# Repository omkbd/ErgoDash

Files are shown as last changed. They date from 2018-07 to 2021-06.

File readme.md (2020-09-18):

# Notice

2019/5/5にファームウェアをアップデートしました。  
それ以前にハードウェアを作製されていた方はアップデートの必要はありませんが、  
アップデートした方は[ビルドガイドの最終項](https://github.com/omkbd/ErgoDash/blob/master/Doc/build.md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)を参照してください。

The firmware has been updated to 5/5/2019.  
If you have previously created hardware, you do not need to update, but if you have updated, please refer to [the last section of the build guide](https://github.com/omkbd/ErgoDash/blob/master/Doc/build-en.md#12-firmware).

# ErgoDash

ErgoDash

[Japanese Read me](https://github.com/omkbd/ErgoDash/blob/master/Doc/ergodash_jp.md)

# Layout

layout

# Parts

[ErgoDash PCB](https://github.com/omkbd/ErgoDash/tree/master/PCB)
 × 2  
[ErgoDash Case](https://github.com/omkbd/ErgoDash/tree/master/Case)
 × 2  
Switch (MX-compatible and Alps switches are supported) × 66-70  
Keycap × 66-70  
1N4148 diode × 66-70  
Arduino Pro Micro × 2  
TRRS jack MJ-4PP-9 × 2  
MJTP1117 switch × 2  
TRRS cable × 1  
Micro USB cable × 1  
M2×5mm screw × 22  
M2×8mm screw × 6  
M2×6mm spacer × 14  
Rubber feet × 8

---Option---  
LED WS2812B × 24  
LED 3mm × 66-70  
470Ω resistor × 66-70  
1kΩ resistor × 2  
NchMOSFET IRLML6344TRPbF × 2  

# Firmware

The ErgoDash uses QMK for its firmware, and the code for it is here:
[QMK - ErgoDash directory](https://github.com/qmk/qmk_firmware/tree/master/keyboards/ergodash)
.  

# Build Guide

[Japanese Build Guide](https://github.com/omkbd/ErgoDash/blob/master/Doc/build.md)  
[English Build Guide](https://github.com/omkbd/ErgoDash/blob/master/Doc/build-en.md)

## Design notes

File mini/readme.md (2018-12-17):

# ErgoDash mini

ErgoDash

[Japanese Read me](https://github.com/omkbd/ErgoDash/blob/master/mini/Doc/ergodashmini_jp.md)

# Layout

layout

# Parts

[ErgoDash mini PCB](https://github.com/omkbd/ErgoDash/tree/master/mini/PCB)
 × 2  
[ErgoDash mini Case](https://github.com/omkbd/ErgoDash/tree/master/mini/Case)
 × 2  
Switch (MX-compatible and Alps switches are supported) × 56  
Keycap × 56  
1N4148 diode × 56  
Arduino Pro Micro × 2  
TRRS jack MJ-4PP-9 × 2  
MJTP1117 switch × 2  
TRRS cable × 1  
Micro USB cable × 1  
M2 screw × 28  
M2 spacer × 14  

---Option---  
LED WS2812B × 20  
LED 3mm × 56  
470Ω resistor × 56  
1kΩ resistor × 2  
NchMOSFET IRLML6344TRPbF × 2  

You can get it
[here](https://dashkbd.booth.pm/items/1011978)
.

# Firmware

The ErgoDash uses QMK for its firmware, and the code for it is here:
[QMK - ErgoDash mini directory](https://github.com/qmk/qmk_firmware/tree/master/keyboards/ergodash/mini)
.  

# Build Guide

Look
[here](https://github.com/omkbd/ErgoDash/blob/master/mini/Doc/build.md)
.

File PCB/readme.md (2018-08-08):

# ErgoDash PCB

ErgoDash PCB  

## 変更履歴

### [rev.1.1]
・圧電スピーカーを追加（試験的）  
・上記に伴うパーツの配置を調整  
・シルク表記を追加

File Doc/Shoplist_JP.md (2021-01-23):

# ErgoDashの買い物リスト[国内]

Cherry MX 互換 スイッチ × 66～70  
https://yushakobo.jp/product-category/switches/  
https://talpkeyboard.stores.jp/?category_id=59cf8860ed05e668db003f5d  

Keycap × 66～70 (基本的に1uのみで構成可、配列によって2uに変更)  
https://talpkeyboard.stores.jp/?category_id=59be183f428f2d49120007b1  
https://talpkeyboard.stores.jp/?category_id=59e2acfaed05e644fd004008  

1N4148 ダイオード × 66～70  
http://akizukidenshi.com/catalog/g/gI-00743/  
https://talpkeyboard.stores.jp/items/59eadbffc8f22c15de001638  

Pro Micro × 2  
https://www.switch-science.com/catalog/1623/  
https://yushakobo.jp/shop/promicro-spring-pinheader/  
https://talpkeyboard.stores.jp/items/5b24504ba6e6ee7ec60063e3

TRRS jack MJ-4PP-9 × 2  
http://akizukidenshi.com/catalog/g/gC-06070/

MJTP1117 switch × 2  
https://www.marutsu.co.jp/pc/i/13351221/  
https://www.digikey.jp/product-detail/ja/apem-inc/MJTP1117/679-2400-ND/1795496  

TRRS cable × 1 (RGB Underglowを使用する場合4極が必要)  
https://www.sengoku.co.jp/mod/sgk_cart/detail.php?code=EEHD-4Z7Y  
https://www.sengoku.co.jp/mod/sgk_cart/detail.php?code=EEHD-4Z84  
https://www.sengoku.co.jp/mod/sgk_cart/detail.php?code=EEHD-4Z87  

Micro USB cable × 1  

M2×5mm ねじ × 22  

M2×8mm ねじ × 6  

M2×6mm スペーサー × 14  
http://www.hirosugi-net.co.jp/shop/c/c10141010/

ゴム足 × 8  

------Option------  
スプリングピンヘッダ12P × 4 ([Helix](https://github.com/MakotoKurauchi/helix)で使用されているものです。)  
https://yushakobo.jp/shop/a01mc-00/  

---Backlight---  
LED 3mm × 66～70  
例(実機未確認)
https://akizukidenshi.com/catalog/c/ctbn3mm/

https://www.aitendo.com/product/10043
(BOXスイッチの場合)

470Ω resistor × 66～70  
http://akizukidenshi.com/catalog/g/gR-16471/  
1kΩ resistor × 2  
http://akizukidenshi.com/catalog/g/gR-16102/  
NchMOSFET IRLML6344TRPbF × 2  
http://akizukidenshi.com/catalog/g/gI-06049/  

---RGB Underglow---  
LED WS2812B × 24  
http://akizukidenshi.com/catalog/g/gI-07915/

又は  
LEDテープ × 2

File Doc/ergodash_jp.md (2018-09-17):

# ErgoDashについて

ErgoDash

## 特徴
・左右分離型  
・Column staggered layout  
・66～70キー（最下段をカスタマイズ可能、最大64パターン?）  
・Cherry MX 互換スイッチ対応  
・Backlight LED対応  
・RGB Underglow対応  
・QMK Firmware 対応  

## キー配列

layout  
上の図が可能な配列です。（わかりにくくてすみません。）  
片手で10パターン、両手で100パターンの配列が選択可能です。  
※両手を同じ配列にする必要はありません。

## パーツ

[ErgoDash PCB](https://github.com/omkbd/ErgoDash/tree/master/PCB)
 × 2  
[ErgoDash Case](https://github.com/omkbd/ErgoDash/tree/master/Case)
 × 2  
Cherry MX 互換 スイッチ × 66～70  
Keycap × 66～70 (基本的に1uのみで構成可、配列によって2uに変更)  
1N4148 ダイオード × 66～70  
Pro Micro × 2  
TRRS jack MJ-4PP-9 × 2  
MJTP1117 switch × 2  
TRRS cable × 1 (RGB Underglowを使用する場合4極が必要)  
Micro USB cable × 1  
M2×5mm ねじ × 22  
M2×8mm ねじ × 6  
M2×6mm スペーサー × 14  
ゴム足 × 8  

------Option------  
スプリングピンヘッダ12P × 4 ([Helix](https://github.com/MakotoKurauchi/helix)で使用されているものです。)  
---Backlight---  
LED 3mm × 66～70  
470Ω resistor × 66～70  
1kΩ resistor × 2  
NchMOSFET IRLML6344TRPbF × 2  
---RGB Underglow---  
LED WS2812B × 24  
又は  
LEDテープ × 2

PCBとケース以外は基本的に国内サイトで入手可能です。  
[ここ](https://dashkbd.booth.pm/items/1011978)
で基本セットを販売しています。

## ファームウェア

QMK Firmwareで動作します。
[QMK - ErgoDash directory](https://github.com/qmk/qmk_firmware/tree/master/keyboards/ergodash)
.  

## 組み立て方

[ここ](https://github.com/omkbd/ErgoDash/blob/master/Doc/build.md)
を見てください。

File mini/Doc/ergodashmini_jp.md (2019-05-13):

# ErgoDash miniについて

ErgoDash mini

## 特徴
・左右分離型  
・Column staggered layout  
・52～56キー（最下段をカスタマイズ可能、最大100パターン）  
・Cherry MX 互換スイッチ対応  
・Backlight LED対応  
・RGB Underglow対応  
・QMK Firmware 対応  

## キー配列

layout  
上の図が可能な配列です。（わかりにくくてすみません。）  
片手で10パターン、両手で100パターンの配列が選択可能です。  
※両手を同じ配列にする必要はありません。

## パーツ

[ErgoDash mini PCB](https://github.com/omkbd/ErgoDash/tree/master/mini/PCB)
 × 2  
[ErgoDash mini Case](https://github.com/omkbd/ErgoDash/tree/master/mini/Case)
 × 2  
Cherry MX 互換 スイッチ × 56  
Keycap × 56 (基本的に1uのみで構成可、配列によって2uに変更)  
1N4148 ダイオード × 56  
Pro Micro × 2  
TRRS jack MJ-4PP-9 × 2  
MJTP1117 switch × 2  
TRRS cable × 1 (RGB Underglowを使用する場合4極が必要)  
Micro USB cable × 1  
M2×5mm ねじ × 22  
M2×8mm ねじ × 6  
M2×6mm スペーサー × 14  
ゴム足 × 8  

------Option------  
スプリングピンヘッダ12P × 4 ([Helix](https://github.com/MakotoKurauchi/helix)で使用されているものです。)  
---Backlight---  
LED 3mm × 56  
470Ω resistor × 56  
1kΩ resistor × 2  
NchMOSFET IRLML6344TRPbF × 2  
---RGB Underglow---  
LED WS2812B × 20  
又は  
LEDテープ × 2

PCBとケース以外は基本的に国内サイトで入手可能です。  
[ここ](https://dashkbd.booth.pm/items/1011978)
で基本セットを販売しています。(準備中)

## ファームウェア

QMK Firmwareで動作します。
[QMK - ErgoDash mini directory](https://github.com/qmk/qmk_firmware/tree/master/keyboards/ergodash/mini)
.  

## 組み立て方

[ここ](https://github.com/omkbd/ErgoDash/blob/master/mini/Doc/build.md)
を見てください。

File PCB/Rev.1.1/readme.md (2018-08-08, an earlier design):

# ErgoDash PCB

このPCBデータはQMK Fimware上のRev.2に対応しています。  

ErgoDash PCB  

### ① pro micro
2か所のうちのどちらか一方に取り付けます。  
シルクが印刷されているほうに取り付けると、コネクタの高さ分ケースを薄くできます。  
### ② MJTP1117 :Reset switch
①で取り付けた位置と逆に取り付けます。  
### ③TRRS jack
シルクに合わせて実装します。
### ④Cherry MX 互換スイッチ  
### ⑤Diode
向きがあるので注意しましょう。  
　　●　　Anode（アノード）  
　　｜  
　　■　　Anode（アノード）SMD用  
　　▽  
　　■　　Cathode（カソード）SMD用  
　　｜  
　　■　　Cathode（カソード）  
### ⑥470Ω resistor（抵抗）  
　　●  
　　｜  
　　■  
　　／  
　　■  
　　｜  
　　●  
### ⑦LED
向きがあるので注意しましょう。  
　　●　　Anode（アノード）  
　　■　　Cathode（カソード）  
### ⑧1kΩ resistor（抵抗）
この一か所のみです。  
　　●  
　　｜  
　　■  
　　／  
　　■  
　　｜  
　　●  
### ⑨NchMOSFET IRLML6344TRPbF
　　■  
　　　　■  
　　■  
### ⑩LED WS2812B
向きがあるので注意しましょう。  
シルクの斜め線はMaster時のものです。Slaveは反対向きに実装します。  
　　■　■  

　　■　■  

### ⑪LED WS2812B用ジャンパ
Master、Slaveによってジャンパする箇所が異なります。  
　　■■■  
　　■■■  
### ⑫RGB LEDテープ用配線取り出しパット
### ⑬I2C用
未検証
### ⑭基板カット位置
レイアウトによりカットします。
### ⑮スペーサ取付穴

### ⑯圧電スピーカー

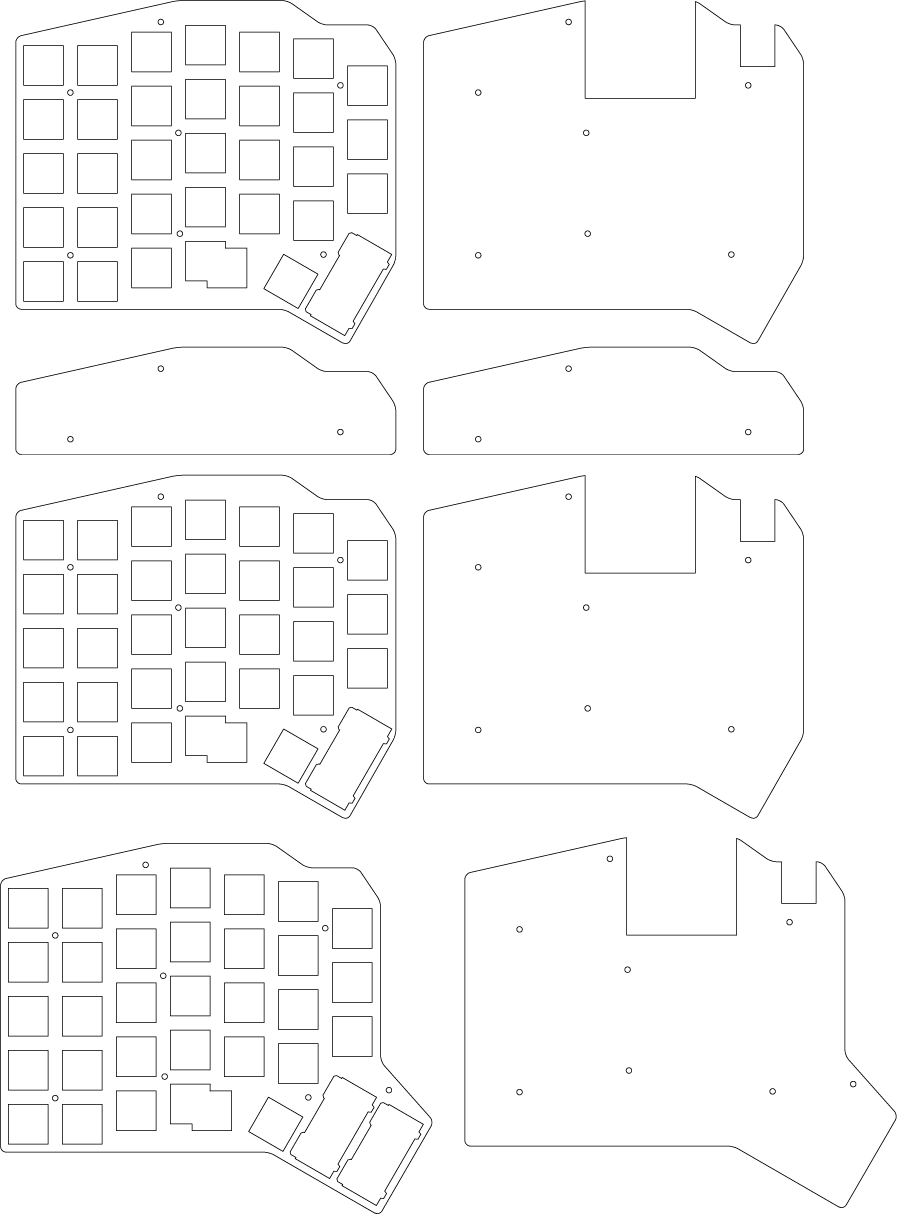
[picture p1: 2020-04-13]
Case/rev1.2/ergodash-rev1-2.png

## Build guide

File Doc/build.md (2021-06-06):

# ErgoDash Build Guide
**一度すべて読んでから組み立てることをお勧めします。**  
※以下の図等はRev.1.1のものになります。Rev.1.2以降はパーツの配置が一部変更されています。

## 概要
assembly  

## 0 準備
組みたいレイアウトによってPCBを切断します。  
PCBcut  
手で力をかければ割れます。  

**以降の番号の3～6と10は基本的に基板の裏側に取り付けます。1と2はどちらにつけても構いません。**  

## 1 ダイオードの取付け
ダイオードの黒いほうが四角いフットプリントに合うように配置します。  
diode  
ダイオードと抵抗の位置を間違えないように注意してください。  
diode  

**Rev1.2では以下のように位置が変更されています。**  
diode  

## 2 Backlight LED用パーツの取付け[Option]
MOSFETを取り付けます。
シルクで四角で囲ってある箇所に1kΩの抵抗を取り付けます。（Rev1.2以降ではBL1kと書いてある方です。）  
1k  

470Ω抵抗を取り付けます。  
  
※一部表面実装の抵抗をつけています。  
**※Pro Microの裏に取り付ける抵抗は表面側に取り付けるか表面実装の抵抗を推奨。**  
**（Pro Microの種類によってはPro Microと干渉します。）**  
Rev1.2以降この問題は解消されました。

## 3 TRRSジャックの取付け  
内側上部の白い四角い枠のシルクに沿って上向きに取り付けます。  

## 4 リセットスイッチの取付け  
中央上部に取り付けます。取り付け可能な場所が2カ所ありますが、Pro Microをつけるのと逆側（縦に並んだピンヘッダのパターンに白い四角い枠が付いていない方）に取り付けます。  

## 5 Undergrow LEDの取付け[Option]
**最新のファームウェアでは以下のようにします。**  
マスターを決める必要はありません。  
以下のように裏側からジャンパします。  
jump2  
左右ともに切れ込みがシルクに合うようにLEDチップを取り付けます。  

**2019/5/5以前のファームウェアでは以下のようにします。**  
~~左右どちらをマスターにするか（USBを指すほう）を決めて、はんだでジャンパします。~~  
~~左手側がマスターの場合は以下のようになります。~~  
jump  

~~LEDチップを取り付けます。~~  
~~マスター側は以下のように切れ込みがシルクに合うように取り付けます。~~  
~~**スレーブ側（逆側）は180度逆向きに取り付けます。**~~  

テープ等で固定してはんだ付けをするとやりやすいです。  
RGB_Left  
RGB_Left_Finish  

## 6 Pro Micro用ピンヘッダの取付け
白い四角い枠がついているほうにピンヘッダを取り付けます。  
**この時点でPro Microを取り付けてはいけません。**  
※スプリングピンヘッダを使う場合は基板側のはんだ付けは不要です。  （この工程でははんだ付けしません。）  
pin  

## 7 スタビライザーの取付け（Rev.1.2以降）[Option]
2Uのキーキャップを使用する場合はアクリルプレートとスイッチを取り付ける前にスタビライザーを取り付けます。(必ずしもつける必要はありません。)  
**スイッチを付けるとスタビライザーは取り付けられなくなります。**  
以下のように組み立てて取り付けます。  
assembly  
スタビライザーの音が気になる場合はグリスを塗布します。（キットには付属していません。）  

## 8 キースイッチの取付け
**スイッチを取り付ける前に部品の取付けやはんだ付けができているか確認します。**  
（TRRSジャックとリセットスイッチは特に注意が必要です。）  
アクリルプレートにキースイッチをはめて取り付けします。  
**スタビライザーをつけている場合はスイッチと基板が浮きやすいので注意しましょう。**  
switch  
switch_complete  

※スプリングピンヘッダを使用する場合は10と12の工程を先に行い、動作確認をすると失敗する可能性が減ります。

## 9 Backlight LEDの取付け[Option]
スイッチの上からLEDを取り付けます。  
丸い穴がアノード（＋）で四角い穴がカソード（-）です。  

## 10 Pro Microの取付け
**作業前にPro MicroをUSBでPCと繋げて動作を確認しておきましょう。**  
取り付ける前にはんだ忘れがないか確認します。  
**Pro Microと基板のTX0が合うか確認して取り付けます。**  
両手とも裏側に取り付けられるようになります。  
取り付けたときにPro Microの浮きがないか確認し、浮きがあればPro Micro下のスイッチの足を少しカットします。  

※スプリングヘッダを使う場合はPro Micro側のみをはんだ付けします。  
スプリングピンヘッダの使い方は下記ページをご参照ください。  
https://github.com/MakotoKurauchi/helix/blob/master/Doc/buildguide_jp.md#pro-micro  

## 11 ケースの組み立て
5mmのねじと6mmのスペーサーを取り付けます。  
spacer  
5mmのねじと8mmのねじを取り付けます。  
case  
ゴム足を取り付けます。  
gom  

## 12 Firmwareの書き込み
以下を参考に書き込んでください。または、QMKで検索すると書き込み方がすぐに出てくるはずです。  
https://docs.qmk.fm/#/getting_started_build_tools  
ErgoDashのFirmwareは以下にあります。  
https://github.com/qmk/qmk_firmware/tree/master/keyboards/ergodash

右手側をマスターにした場合はqmkのkeymap内のconfig.hファイルで
`MASTER_RIGHT`を指定してファームウェアをビルドする必要があります。  
https://docs.qmk.fm/#/config_options?id=defines-for-handedness

BacklightとUnderglowを点けるにはkeymap内のrules.mkに以下を追記します。AUDIOについてはサポート外です。  
`BACKLIGHT_ENABLE = yes`  
`RGBLIGHT_ENABLE = yes  `  
初期設定値として、Underglow LEDは点灯しますが、Backlight LEDは消灯状態となります。Backlight LEDの点灯を確認する場合は、 `BL_TOGG` キー(defaultキーマップでは `Lower + Raise + S`)を押してください。

**5の工程で2019/5/5以前のファームウェアを使用した場合はrev1/config.h内の以下の行をコメントアウトしてください。**  
`#define RGBLIGHT_SPLIT`  
`#define RGBLED_SPLIT { 12, 12 } `

初めての方は以下のツールを使うことをお勧めします。（これらを使用する場合LED系は点灯しません。）  
https://config.qmk.fm/#/ergodash/rev2/LAYOUT  
https://github.com/qmk/qmk_toolbox

キーキャップをつけて完成!!!!!  
finish  

## EXT Firmwareの書き換え
VIAというツールを使えばキーマップをGUI上で変更できます。  
https://github.com/the-via/releases/releases/tag/v1.3.1  

ErgoDashのVIA用ファームウェアは以下にあります。  
https://github.com/omkbd/ErgoDash/tree/master/Firmware  
ergodash_rev1_via.hexをQMKtoolbox等で書き込んでから使用してください。  

書き込みができたらVIAを起動してFile＞Import KeymapからErgoDash.jsonを読み込んでください。

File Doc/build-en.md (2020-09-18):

# ErgoDash Build Guide
**Feel free not to read completely, but pay attention when installing the Pro Micro!!!!!!**
Note: The below diagrams are for rev 1.1. For rev 1.2. and up, the part placement is slightly different.

Translated, with extra build notes (From: build.md https://github.com/omkbd/ErgoDash/commit/d12e8f7fd414fe89d38b77b3b0e6a0af4b639a47)

## Overview
assembly

## 0 Preparation
Remove extra thumb key section if desired.
PCBcut
carefully break by hand

**Note:
Components in steps 3-6 and 10 must be inserted on the bottom of the board.
Components in steps 1 and 2 can be installed on the top or bottom.**

## 1 Install Diodes
When installing diodes the black stripe is towards the square pad
(diodes are all 1 square 1 round pad)
(resistors are all both round pad)
diode

Note the positions of diodes and resistors to avoid mistakes
diode

**Rev 1.2 positions are changed as below.**
diode

## 2 Backlight LED [optional]
Install the MOSFET (Install note/suggestion: pre-soldering the single pad worked well)
Install 1kΩ resistor in silk rectangle as noted 。(Silk screen notation is improved on rev 1.2 [BL1k])
1k

Install 470Ω resistors


-Note: Photo has a few surface mount resistors combined with through-hole
**(Rev 1.1) For the resistor found under the pro-micro: a surface mount resistor, or installing resistor on opposite side may be preferred to prevent interference (moved in rev 1.2)**

## 3 TRRS Jack
On the underside of the board, install the TRRS Jack as indicated by the silkscreen.

## 4 Install reset switch
The reset switch needs to go the underside of the board.
At the top of the board there are 2 locations for the pro-micro.
Pro Micro will be installed where the rectangular outline is printed
Reset switch is installed where the rectangular outline is not seen
Compare with photo on Step 6

## 5 Underglow LED [optional]
**The latest firmware is as follows.**  
There is no need to decide on a master.  
Jump from the back as follows.  
jump2  
Attach the LED chip so that the cut on both sides matches the silk.

**The firmware before 2019/5/5 is implemented as follows.**  
~~Choose which of the pair (left or right) will be master (where the USB cable will be attached), and solder the jumpers as below.~~  
~~The board in the photo below has the jumpers soldered for left hand master. The left hand board is on the right, and the right hand board is on the left.~~  
~~In the two diagrams, the upper image is for left hand master (labelled 左マスター), and the lower image is for right hand master (右マスター).~~  
jump

~~Install LED WS2812B~~  
~~**IMPORTANT**~~  
~~-On Master half, LED corner will Match the silkscreen~~  
~~-On Slave half, LED corner needs to be 180 from silkscreen~~  

-Installation notes:
  -use tape to hold in place, solder one side, remove tape, then solder other
  -Notes from first time soldering with these LED:
    -I attempted to pre-solder pads with bad results (As recommended for other surface mount I did before)
    -Leaving iron on too long appeared to melt the casing of the LED (Use fine tip if you have it? I didnt)
    -1sec on pad to pre-heat, then off and come back with iron and solder is what worked best for me

RGB_Left
RGB_Left_Finish

## 6 Pro Micro header  and reset switch installation
On the underside, attach Headers where you see the rectangular outline on silkscrean  (It is in the correct position on each side of the board)
**Do Not attach Pro Micro Yet**
When using spring headers, soldering the header to the board is unnecessary.

pin

## 7 Install Stabilizer （rev 1.2 or Later only）[optional]

(I used Rev 1.1 without Stabilizers, translation below)

If you will be using 2U keycap(s), then attach the stablizer(s). (If necessary; it's not always required).
**Note: Once the switch is installed, it's no longer possible to attach the stabilizer.**
Put together and attach as shown below.
assembly
If you're concerned about the noise of the stabilizer then apply grease (not included in kit).

## 8 Install Switches and Plate
Make sure all other components are installed before adding switches.
Place the plate with keyholes over top the PCB and snap in and solder switches.
Start with 4 corners in the plate to ensure alignment.
After the first 4 are soldered in, install remaining switches.
Just above the "ergoDash Rev 1.2" sign, there is two possible locations for the switch.
The recommanded location is at the right side for the right part of the keybord (to use it as arrow keys).
And at the left side for the left part of the keyboard (as a modifier)
See this picture (https://raw.githubusercontent.com/omkbd/picture/master/Ergodash.jpg)

switch
switch_complete

## 9 Backlight LED Install [optional]
Install the LEDs from the top on each switch
Round Pad  anode（＋）(Long LED Leg)
Square Pad  cathode（-) (Short Leg)
-Can be installed later (Except for the LED under pro-micro)

## 10 Pro Micro Install
**Before proceding connect the Pro Micro to a PC via USB and confirm it's working.**
-Confirm the TX0 lines up (USB port sandwiched between both PCBs)
-Check that all solder connections underneath the Pro Micro are done.
-Confirm no contact between Pro Micro and components (add insulating tape if desired)
-For spring headers, solder is required on the Pro Micro side.
-After installation, confirm the Pro Micro is properly seated. If not, cut the legs of the switch under the Pro Micro slightly.
-Trim headers after testing.

## 11 Case Assembly
Install the 5mm screws and 6mm spacers from the top。

spacer

Install 5mm and 8mm screws according to the diagram。

case

Install Rubber feet

gom

## 12 Firmware

QMK Build Guide
https://docs.qmk.fm/#/getting_started_build_tools

ErgoDash Firmware
https://github.com/qmk/qmk_firmware/tree/master/keyboards/ergodash

If the right hand side is the master, you need to build the firmware by specifying `MASTER_RIGHT` in the config.h file in the key map of qmk.  
To turn on Backlight and Underglow, add the following to rules.mk in the keymap.  
`BACKLIGHT_ENABLE = yes`  
`RGBLIGHT_ENABLE = yes  `
As the default setting, Underglow LEDs turn on, but Backlight LEDs don't turn on. If you want to confirm whether Backlight LEDs work normally or not, press the `BL_TOGG` key (this key is assigned to `Lower + Raise + S` on the default key map).

**If you used firmware 5/5/2019 or earlier in step 5, comment out the following line in rev1 / config.h.**  
`#define RGBLIGHT_SPLIT`  
`#define RGBLED_SPLIT { 12, 12 } `

Attach the keycaps, and you're done!!!!!

finish

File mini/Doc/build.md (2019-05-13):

# ErgoDash mini Build Guide

**基本的にErgoDashと同じなので、省略して書いています。**  
必要に応じて以下のページを参照してください。  
https://github.com/omkbd/ErgoDash/blob/master/Doc/build.md

PCB  

## 0 準備
組みたいレイアウトによってPCBを切断します。  
手で力をかければ割れます。  

**以降の番号の3～6と10は基本的に基板の裏側に取り付けます。**  

## 1 ダイオードの取付け
ダイオードの黒いほうが四角いフットプリントに合うように配置します。  
ダイオードと抵抗の位置を間違えないように注意してください。  

## 2 Backlight LED用パーツの取付け[Option]
MOSFETを取り付けます。
シルクでBL1kと書かれている四角で囲ってある箇所に1kΩの抵抗を取り付けます。  
470Ω抵抗を取り付けます。  
※Pro Microの裏に取り付ける抵抗は表面側に取り付けるか表面実装を推奨。(Pro Microの種類によってはPro Microと干渉します。)  

## 3 TRRSジャックの取付け  
シルクに沿って取り付けます。  

## 4 リセットスイッチの取付け  
Pro Microをつけるのと逆側に取り付けます。  

## 5 Undergrow LEDの取付け[Option]
**最新のファームウェアでは以下のようにします。**  
マスターを決める必要はありません。  
以下のように裏側からジャンパします。  
jump2  
左右ともに切れ込みがシルクに合うようにLEDチップを取り付けます。  

**2019/5/5以前のファームウェアでは以下のようにします。**  
~~左右どちらをマスターにするか（USBを指すほう）を決めて、はんだでジャンパします。~~  
~~左手側がマスターの場合は以下のようになります。~~  
jump  

~~LEDチップを取り付けます。~~  
~~マスター側は以下のように切れ込みがシルクに合うように取り付けます。~~  
~~**スレーブ側（逆側）は180度逆向きに取り付けます。**~~  

テープ等で固定してはんだ付けをするとやりやすいです。  
RGB_Left  
RGB_Left_Finish  

## 6 Pro Micro用ピンヘッダの取付け
白い四角い枠がついているほうにピンヘッダを取り付けます。  
**この時点でPro Microを取り付けてはいけません。**  
※スプリングピンヘッダを使う場合は基板側のはんだ付けは不要です。  （この工程でははんだ付けしません。）  

## 7 スタビライザーの取付け[option]
2Uのキーキャップを使用する場合はスイッチを取り付ける前にスタビライザーを取り付けます。(必ずしもつける必要はありません。)  
**スイッチを付けるとスタビライザーは取り付けられなくなります。**  
以下のように組み立てて取り付けます。  
assembly  
スタビライザーの音が気になる場合はグリスを塗布します。（キットには付属していません。）  

## 8 キースイッチの取付け
**スイッチを取り付ける前に部品の取付けやはんだ付けができているか確認します。**  
（TRRSジャックとリセットスイッチは特に注意が必要です。）  
アクリルプレートにキースイッチをはめて取り付けします。  
**スタビライザーをつけている場合はスイッチと基板が浮きやすいので注意しましょう。**  

※スプリングピンヘッダを使用する場合は10と12の工程を先に行い、動作確認をすると失敗する可能性が減ります。

## 9 Backlight LEDの取付け[Option]
スイッチの上からLEDを取り付けます。  
丸い穴がアノード（＋）で四角い穴がカソード（-）です。  

## 10 Pro Microの取付け
**作業前にPro MicroをUSBでPCと繋げて動作を確認しておきましょう。**  
取り付ける前にはんだ忘れがないか確認します。  
Pro Microと基板のTX0が合うか確認して取り付けます。  
両手とも裏側に取り付けられるようになります。  
スプリングヘッダを使う場合はPro Micro側ははんだ付けします。
取り付けたときにPro Microの浮きがないか確認し、浮きがあればPro Micro下のスイッチの足を少しカットします。

※スプリングヘッダを使う場合はPro Micro側のみをはんだ付けします。  
スプリングピンヘッダの使い方は下記ページをご参照ください。  
https://github.com/MakotoKurauchi/helix/blob/master/Doc/buildguide_jp.md#pro-micro  

## 11 ケースの組み立て
表面に5mmのねじと6mmのスペーサーを取り付けます。  
裏面に5mmのねじと8mmのねじを取り付けます。  
ゴム足を取り付けます。  

## 12 Firmwareの書き込み
以下を参考に書き込んでください。または、QMKで検索すると書き込み方がすぐに出てくるはずです。  
https://docs.qmk.fm/#/getting_started_build_tools  
ErgoDashのFirmwareは以下にあります。  
https://github.com/qmk/qmk_firmware/tree/master/keyboards/ergodash

右手側をマスターにした場合はqmkのkeymap内のconfig.hファイルで
`MASTER_RIGHT`を指定してファームウェアをビルドする必要があります。
https://docs.qmk.fm/#/config_options?id=defines-for-handedness

BacklightとUnderglowを点けるにはkeymap内のrules.mkに以下を追記します。AUDIOについてはサポート外です。  
`BACKLIGHT_ENABLE = yes`  
`RGBLIGHT_ENABLE = yes  `

**5の工程で2019/5/5以前のファームウェアを使用した場合はrev1/config.h内の以下の行をコメントアウトしてください。**  
`#define RGBLIGHT_SPLIT`  
`#define RGBLED_SPLIT { 10, 10 } `

初めての方は以下のツールを使うことをお勧めします。（これらを使用する場合LED系は点灯しません。）  
https://config.qmk.fm/#/ergodash/rev2/LAYOUT  
https://github.com/qmk/qmk_toolbox

キーキャップをつけて完成!!!!!

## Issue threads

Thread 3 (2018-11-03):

ErgoDash mini pcb missing

CicelyWang, 2018-11-03:
As is. I have more interested with the mini type of ergodash. Hope the kicad pcb files could be upload.

omkbd, 2018-11-08:
Sorry, I am preparing it now.

omkbd, 2018-12-17:
I uploaded the PCB data!

Closed 2018-12-17.

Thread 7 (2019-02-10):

Parts list does not include speaker

GreenShadowMaker, 2019-02-10:
It appears There is a Speaker on the PCB ver 1.1, what is the recommended part number?

omkbd, 2019-02-12:
The speaker is as follows:
http://akizukidenshi.com/catalog/g/gP-05723/

This is just a trial implementation.
It can not be used with RGB LEDs.

Closed 2019-02-15.

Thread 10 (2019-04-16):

Supported Stabilizers

SF-BlueGuy, 2019-04-16:
Hello,
Just having some issues with the build.

1. I'm using [zeal stabs](https://zealpc.net/products/zealstabilizers) and I can't seem to place two of them on the thumb cluster. They seam to overlap just enough to not allow both to properly seat. Just wondering if anyone has has used these successfully in this orientation, or do I have to use the cherry stabs

2. Even after using just one zeal stab, the acrylic switch plate doesn't seem to sit well on it making it rather challenging to sit switches on the plate and into the pcb for soldering.

Just curious if anyone else having these issues with the cherry stabs before I go out and order a few.

Thanks

omkbd, 2019-05-02:
Sorry, I examined only this stabilizer.
https://kbdfans.cn/collections/keyboard-stabilizer/products/transparent-pcb-stabilizers-27

Closed 2019-06-05.

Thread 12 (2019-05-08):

the documentation is extremely confusing!

rmarinbe, 2019-05-08:
I have board revision 1.2 and I found the building documentation (English) very confusing and mixed with japanesse.
For example, there are two possible locations for the pro-micro, but it is not specified which side the pro-micro should be attached
for example, it says:

"but pay attention when installing the Pro Micro!!!!!! Note: The below diagrams are for rev 1.1. For rev 1.2. and up, the part placement is slightly different."

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

for the master and slave in the latest firmware ( after this date 2019/5/5): Do I need to do any soldering (jumper) as it is shown below or not?

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

omkbd, 2019-05-13:
I'm sorry I confused you.

"but pay attention when installing the Pro Micro!!!!!! Note: The below diagrams are for rev 1.1. For rev 1.2. and up, the part placement is slightly different."
>>Plaese read section 6.
https://github.com/omkbd/ErgoDash/blob/master/Doc/build-en.md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

for the master and slave in the latest firmware ( after this date 2019/5/5): Do I need to do any soldering (jumper) as it is shown below or not?
>>The latest version is as follows.
https://github.com/omkbd/picture/blob/master/Jump2-en.png

Closed 2019-06-05.

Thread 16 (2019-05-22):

Facing issues sourcing the MJ-4PP-9

Strayer, 2019-05-22:
Hey, this is a little off topic, sorry for that. I'm having issues sourcing the MJ-4PP-9 TRRS jack in Europe (or anywhere outsite of Japan, to be precise).

I ordered some 4 pol TRRS jacks, but the connections on those will require some hacking on the PCB – so any tips where I could find the MJ-4PP-9 internationally would be greatly appreciated!

The ones I ordered are these:
FC68125
https://cdn-reichelt.de/documents/datenblatt/C160/4%20POLE%20JACKS.pdf

I did find these on AliExpress, which are _very_ similar:
https://datasheet.lcsc.com/szlcsc/Made-in-China-PJ-320A_C12569.pdf

There are some differences in the spacing of the pins (around 0.2mm), but that could fit.

GreenShadowMaker, 2019-05-23:
20PCS DIP PJ320A 3.5MM Headphone Audio Socket PJ-320A PJ320 PJ-320 4 pins Audio interface
https://s.click.aliexpress.com/e/pGyft1Q

Is what I used. (Fits perfect) After getting a url from omkbd

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

Strayer, 2019-05-23:
Hey @GreenShadowMaker, thanks for confirming! Those are the ones I purchased on AliExpress, so I guess I'm fine. I'm still debating wether I should modify the footprint, but the sizes are off by such a tiny amount (0.1mm - 0.2mm) that I might just risk it.

Closed 2019-06-05.

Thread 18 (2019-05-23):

LEDs and inconsistant keys

nutimnot, 2019-05-23:
Hello,

I built this board yesterday and have been having some issues. First I cannot figure out how to turn the LEDs on. I flashed my custom .hex file to the keyboard but other than that i cannot get the lights to turn on. I update the file like the instructions say but i'm not sure how they're supposed to populate to the board itself.

Secondly i've been having some issues getting keys to work sometimes. For example when i built the board, I couldn't get my 7 key to work, i thought I had soldered it incorrectly but everything else works. Now the 7 works fine and the enter key doesn't work without changing anything. Also sometimes the keys need to be pressed a few times before they'll register with the computer. Any assistance would be greatly appriciated, thank you!

omkbd, 2019-05-24:
・First question
Press BL_TOGG or RGB_TOG.

・Second question
I can only think of checking the soldering.

nutimnot, 2019-05-24:
Thanks for the reply! How do I press BL_TOGG or RGB_TOG?

brethash, 2019-05-24:
@nutimnot could you post a couple pictures of the boards? It might help rule out soldering as the culprit.

nutimnot, 2019-05-24:
@brethash here are some pictures. I got home just now and added some more solder to the mis-behaving keys and reflashed that side of the keyboard to no avail, the entire HJKL:" row is dead.

for reference, in the picture the middle row is the HJKL:" row
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

GreenShadowMaker, 2019-05-25:
I haven't had working RGB LEDs on either of the 2 I built.. I'm pretty sure I screwed up my first build.(backwards on one side) not sure why my second didn't work.

But, in your photos you haven't done the RGB jumper connetion.

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

GreenShadowMaker, 2019-05-25:
For an entire row that stopped working, it may be the pro-micro connection.

nutimnot, 2019-05-25:
@GreenShadowMaker how would i go about fixing that kind of issue?

nutimnot, 2019-05-30:
I managed to fix the issues with the HJKL row. One of the points on the Pro micro wasn't soldered well, so I remelted it and now it's fully functional (typed this reply on the keyboard). If anyone knows why the LEDs aren't working let me know. I don't have any resistors set up, the kit only came with diodes.

brethash, 2019-06-03:
@nutimnot you won't need any additional resistors for the undermount LEDs to work. The resistors are only needed for the backlight/switch LEDs.

If you're using the default keymap for the keyboard, try flashing @GreenShadowMaker 's keymap. It seems like his has the undermount LEDs on by default (at least thats what it seemed like when I flashed it anyway). The layers in his keymap are also a bit easier to work with in my opinion.

nutimnot, 2019-06-03:
@brethash where can I find their keymap?

brethash, 2019-06-03:
The keymap is [here](https://github.com/qmk/qmk_firmware/tree/master/keyboards/ergodash/rev1/keymaps/greenshadowmaker) and the layout itself is [here](https://github.com/qmk/qmk_firmware/blob/master/keyboards/ergodash/rev1/keymaps/greenshadowmaker/keymap.c). To toggle the `adjust` layer, the raise and lower keys are pressed at the same time (for me they were the keys directly below the `B` and the `N`.

nutimnot, 2019-06-03:
Awesome thank you! Now I'd just try flashing it with QMK and see if it works yeah?

brethash, 2019-06-03:
Yep! You should be able to build/flash it with `make ergodash/rev1:greenshadowmaker:avrdude` from the root of the `QMK` folder.

nutimnot, 2019-06-05:
@brethash how do you do that using the QMK toolbox?

brethash, 2019-06-05:
@nutimnot that's a good question! I've actually not used the QMK toolbox before; I always just build and flash from the command line, so I'm not sure how it works. 😞

nutimnot, 2019-06-05:
I flashed it but it didn't turn on the LEDs so i'm not sure. Maybe I will try something else or test to see if the LEDs work at all I guess. Thank you @brethash for all your help my guy

omkbd, 2019-06-05:
You haven't done the RGB jumper connetion.
You have to read this.
https://github.com/omkbd/ErgoDash/blob/master/Doc/build-en.md#5-underglow-led-optional

nutimnot, 2019-06-05:
@omkbd So I just have to solder those two connections at the top of the board? I shouldn't need anything other than some solder, right? I don't have any resistors installed or anything. I'll try it out this week

nutimnot, 2019-06-07:
I got it to work, thank you @omkbd and @brethash for y'alls help <3

Closed 2019-06-07.

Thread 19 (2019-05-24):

No right side backlight LEDs lit

brethash, 2019-05-24:
I was just finishing up my Ergodash and wanted to test the backlight LEDs before I went ahead and soldered all 34 onto the boards. I noticed that the right side LEDs don't seem to light up, but the left side (my master side in this case) appear to all work as expected. I loaded up the `greenshadowmaker` keymap, but I don't really see any sort of configuration that would indicate that _only_ the left side should be backlit.

Before I go and desolder the mosfet, I wanted to double check that there isn't any firmware options I should check. Additionally, I'm 99% sure that the polarity is correct on the 3 LEDs I installed on the right. I even tried soldering one in with the reverse polarity and one with the correct polarity just to prove to myself that I've got them in right!

Thanks again for any help!

GreenShadowMaker, 2019-05-25:
The mosfet is missing in this photo isn't it?

brethash, 2019-05-28:
Hey @GreenShadowMaker ! First of all, thanks for putting together this keymap!

The mosfet is on the board, just above the rightmost RGB LED on bottom row of the RGB LEDs. For what its worth, I did add just a touch more solder to the connection on the side with one lead (the right side of mosfet in this image), but I got the same result.

GreenShadowMaker, 2019-05-29:
Ah, it just blended in too well in the photo. I can see solder.. but the black chip outline was hard :)

I built 1.1 that doesn’t have the extra resistor next to the bl one. Looks like it may be for the speaker?

brethash, 2019-06-03:
So I got back home after the holiday weekend and removed the old mosfet and tried another in its place. Same result. :(

I also double checked all the resistors on the board and they all appear to be in the correct location according to the left side (that works!) and the updated build guide. I suppose I'll just solder on the rest of the backlight LEDs for fun and hope for the best.

omkbd, 2019-06-13:
I think that it is a solder defect of MOSFET.

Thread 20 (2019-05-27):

Have you consider to support hotplug socket for switch ?

hpo14, 2019-05-27:
just like ErgoDox's "Change It Youself" product, it use the hot plug socket to let user
can easily change switches.

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

omkbd, 2019-05-29:
It is under development.
Look at my twitter.
https://twitter.com/omkbd

Closed 2019-06-05.

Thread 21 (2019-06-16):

Printing PCB

dmcgits, 2019-06-16:
Hi, I’m hoping to print the ergodash. Thanks so much for posting your design!

Are the gerber files in the subfolder of V1.2 all I need to submit to the main chinese pcb printers? Or do I need to export other files from KiCad.

I know a bit about cables/3d/programming but I’ve never designed/printed circuit boards. Apologies is this is obvious/already covered.

Thanks again for your design and generosity.

dmcgits, 2019-06-27:
A redditor in the states got back to me, he was able to print by submitting the zip file in the gerber folder 👌

Closed 2019-06-27.

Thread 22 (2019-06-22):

Idea: Rotary Encoder

dmcgits, 2019-06-22:
Have you ever considered one of these for the ergodash? Apologies that I’m suggesting rather than attempting it myself, I’m still new to circuits/kiCad.

The Preonic’s rotary encoder is pretty neat and I’d love to replace maybe my top row innermost keys (currently -, + in the laser image) with a rotary encoder. Alternatively, it could be thumb accessible on the snap-off section.

The Preonic uses a twisting stick style dial, but with an ortho being so friendly to home row users it’d be slick if it were a drum you could roll with a thumb or forefinger without flexion.  Like a Logitech G810 but the width of a keycap :)

Since Jack added one to Preonic I’m guessing QMK support is there too.

Thanks for reading and thanks again for your generosity!

brethash, 2019-06-23:
For what its worth, I'd love something like this and have been thinking about if it could work. I was literally just telling a friend of mine today how much I've been loving my Ergodash, but that I was considering building an Iris just to play around w/ the addition of a rotary encoder.

I did notice during the build that there seem to be some indications on the PCB for an I2C interface, but I'm not 1000% sure how to access that. If that were possible, you could theoretically leverage it to add an I2C-ready rotary encoder like [this](https://hackaday.com/2018/04/15/rotary-encoders-become-i2c-devices/), which I think you can buy [here](https://www.ebay.com/itm/I2C-Encoder-V2-RGB-Encoder-Knob-connector/173696523407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) (I think!).
@omkbd I don't suppose you might be able to shed a little light on this potential implementation?

omkbd, 2019-06-23:
I am already working on the implementation of the rotary encoder. However, I am worried about where to place it. I think that the position of the thumb is the best.

brethash, 2019-06-23:
I was also thinking somewhere around the thumb cluster. I'm curious how you were going about the implementation? Would this be an add-on for the current v1.2 board or would this be something for a v1.3? I was thinking of just whipping up a little enclosure for the encoder and its pcb that attaches with the top case plate via the screw at the top of the thumb cluster. Then I was just going to throw it on my 3d printer and see what it takes me. :)

dmcgits, 2019-06-24:
Thanks so much @omkbd for responding, also @brethash!

What if you had a V1.2 and a V1.2R, the R being a version with rotary encoder?

I’m having a think about the positioning and will sketch them down, maybe it’ll be useful.

omkbd, 2019-07-04:
Testing...
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

dmcgits, 2019-07-04:
Haha, lovely!

dmcgits, 2019-10-06:
Hi @omkbd, how did the testing go? Is there somewhere you’d rather I ask questions? Maybe Discord?

MattBlissett, 2019-11-12:
In case anyone else wants to hack this on an existing board:

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

I'm not using the backlight or audio, so these two pins are available, and there's conveniently a trace bringing them across the board.

It's then simple to add support in QMK: https://github.com/MattBlissett/qmk_firmware/commit/16ed43b4dc5c786f69ceaa68fbfaec1b29208507

The encoders are jammed into the MX plate holes with some bits of folded cardboard. Since the keyboard is going to stay on my desk, this is probably OK for a while.

> whipping up a little enclosure for the encoder and its pcb that attaches with the top case plate via the screw at the top of the thumb cluster

That would be much neater. Another option is to 3D print or use a tiny PCB that fits in the MX hole, like [this one](https://www.reddit.com/r/MechanicalKeyboards/comments/chs82g/designed_a_new_adapter_for_installing_rotary/) (except that's for handwired keyboards).

> Will it be difficult to make it work on both sides of pcb like your switch mounts do?

I doubt it, as the wiring is symmetrical:

```
A C B
| | |
[===]
 | |
 D E
```

`C` is the common pin, `A` and `B` are the signals when rotating. `E` and `F` are the push button.

n8gray, 2019-12-04:
Oh dear lord, now I can't live without this.  I've been debating between Redox and ErgoDash but this decides it.

dyamon, 2021-02-09:
Hey @MattBlissett , noob-ish guy here! Would you mind giving a bit more details on how to connect the wires on the encoder side? Do you get both rotation and push botton functionalities?

MattBlissett, 2021-02-09:
Hi,

I don't use the push button of the encoder -- the ones I bought are rather stiff to push, so I didn't feel I needed it.  There's also nowhere to connect it, unless you swapped one of the nearby keys for a double-height one and used the freed-up connection, but I don't see the benefit.

There was a typo in my comment above, which I've fixed (above too):

```
A C B
| | |
[===]
 | |
 D E
```

The middle pin `C` is the common pin, which I connected to the unused audio trace.  `A` and `B` are the signals when rotating, they are activated in a special pattern ([Gray code](https://en.wikipedia.org/wiki/Gray_code)) when rotating the knob.  These I connect to the backlight trace:

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

If you connect `A` and `B` the "wrong" way around, just change the key mappings in your QMK code accordingly.

dyamon, 2021-02-09:
Thank you very much!

> There's also nowhere to connect it, unless you swapped one of the nearby keys for a double-height one and used the freed-up connection, but I don't see the benefit.

Oh I see, that's because you installed it in the extra thumb key, which I removed. I'm planning on putting it next to it where I have the connection directly under the encoder. So it seems like I might be able to get the push button functionality as well.

> The middle pin `C` is the common pin, which I connected to the unused audio trace. `A` and `B` are the signals when rotating, they are activated in a special pattern ([Gray code](https://en.wikipedia.org/wiki/Gray_code)) when rotating the knob. These I connect to the backlight trace

Thanks, this is super useful!

gregor-on, 2023-02-22:
it can be done relatively easy, by utilising led's pins from the board Arduino, and also I've been able to add displays by changing D0 to D2 and attaching display there see at gdoes.art , I'm not great at this github thing, not sure how to share it. message me and I'd like to attach it here including CAD files etc. btw I used vertical encoders, mouse - like setup. Ergodash is a great platform to play with, it is a shame it is so hard to get it working with VIA tho

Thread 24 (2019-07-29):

Right half keys not working

callebjorkell, 2019-07-29:
I've been struggling to get the right half of my ergodash to work, and at this point I cannot figure out if it's a hardware or a software issue. When I plug the keyboard in, the LEDs turn on, and the keys on the left side works, while the keys on the right hand side does nothing.

My situation is:

* LEDs on both sides turn on when I plug in the TRRS cable
* I'm using sparkfun pro micros
* TRRS pins have continuity (checked with a multimeter) between all four pins. Maybe someone could tell me which pins on the pro micro they are connected to so I can check all the way from pro micro to pro micro? Can't really follow the traces.
* Both halfs work if I plug them in directly with the USB cable
* I've tried various settings for qmk to try to troubleshoot, but nothing has made a difference, and right now the only tweak I have is `RGBLIGHT_ENABLE = yes` in `rules.mk`
* building and flashing with `sudo make ergodash/rev1:default:avrdude` on latest qmk master (eafd38e2a16cd00e95e00c5ca4efc364d3ccf3e4)

Are you able to point me towards what I could do to try to troubleshoot, and/or confirm that I've got everything soldered in the right place?

Front:
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

Back:
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

Appreciate the help/time!

callebjorkell, 2019-07-29:
I think I found the pin as well. I have a good connection between the pin marked "SCL - 3" in this diagram: 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

I hope that sounds right?

GreenShadowMaker, 2019-08-01:
https://imgur.com/a/ect63fa
Is the back of mine, working.

Pro micro orientation would seem to be fine

-I don’t think I tried mine before I had all the switches installed

Probably not it since your rgb light up.(mine didn’t from what I remember. but remove the solder from the selector pads. For the rgb on the master and see if it works.   I think I overheated/fried my rgb or reversed one, I didn’t get them to work. But my second half had issues until removed jumper solder from master.

callebjorkell, 2019-08-01:
Tried to desolder the pads, but unfortunately there is no change to how the keys work, but LEDs are now off of course.

callebjorkell, 2019-08-07:
It seems likely that this issue is caused by my use of the sparkfun pro micro. I tried to mount a "Tenstar robot" pro micro onto the half that wasn't working before, and now it works fine as slave, but the one with the sparkfun pro micro still does not work as a slave, even though it's fine as master. I even tried to build a spare PCB that I had, put the sparkfun pro micro on that, and it exhibits the exact same problems as the original one I built. In short, I have three halves:
* 1 and 2 with sparkfun => both work fine as master, neither as slave
* 1 with tenstar, 2 with sparkfun => 1 works fine as either slave or master, 2 only as master.
* 3 and 2 with sparkfun => both work fine as master, neither as slave. Both work fine as master and the tenstar 1 as slave.

I chose the sparkfun on color alone, since I have an acrylic case and wanted the white PCB with the red pro micro, so this feels silly now. Does anyone know in which way the sparkfun pro micro is different, and possibly a way to work around this issue to make both my spark fun pro micro halves work? I'm hoping this can be corrected in software. I've got the controllers soldered onto the board, so I doubt I'll be able to get them desoldered without maiming the board. :disappointed:

callebjorkell, 2019-09-09:
Gave up, made another one with an elite-c, works fine now. I'll close the issue as I scavenged the these boards for parts, and hence can't confirm that any suggested fix is working anymore anyway. Still irks me that I don't know what was wrong with it though.

Strayer, 2020-01-20:
So, I'm having the same problem with my build. It found references that Sparkfun Pri Micros have J1 jumpers jumped and need to be desoldered for Lets Split keyboards to work, maybe this is the same issue here? I'm probably not using genuine Sparkfun Pro Micros, but still will have to check that :/

nchrisdk, 2020-02-15:
I had the same issue. I just "desoldered" one of my failed attempts and removed (with force) Pro Micro. J1 jumper was not desoldered...

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

JonahBranch, 2022-09-27:
I'm having problems with the right half as well. Made 3 sets of keyboards and only the left hand will flash. The right hand always responds with "programmer not responding" when trying to flash, and that's when it's plugged in directly to the computer.

It's possible that those microcontrollers happen to be defect, but the fact it happened 3 times on the right hand makes me suspicious. I'm going to try reinstalling the bootloader on the nonfunctional controllers

isidroas, 2023-05-08:
`#define SPLIT_USB_DETECT` in `config.h`

source: https://www.reddit.com/r/olkb/comments/oh65me/comment/h4nbqzo/?utm_source=share&utm_medium=web2x&context=3

Closed 2019-09-09.

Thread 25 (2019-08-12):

A problem I don't understand. Please help me

kien242tran, 2019-08-12:
I watched your design. But there is a problem I can't understand. It is located at the way you connect the led lights WS2812B. According to datasheed, the function of pin 2 is "Control data signal output" and pin 4 is "Control data signal input",  but you're connected backwards. Is there a problem here?

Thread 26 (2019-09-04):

Confusion about spacers

Strayer, 2019-09-04:
In the japanese shopping list, there is only one spacer (6mm):

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

The english build guide mentions 5mm and 6mm:

> Install the 5mm and 6mm spacers from the top。

https://github.com/omkbd/ErgoDash/blob/master/Doc/build-en.md#11-case-assembly

I assume the shopping list is correct and this is an error in the build guide?

Closed 2020-09-18.

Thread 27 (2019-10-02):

Plans to add revision 1.3 or 2.0 PCB schematics and spec?

richerve, 2019-10-02:
I've seen in your twitter account @omkbd pictures of PCBs version 1.3 and 2.0, this last one with hot-swappable switches and what it looks like a usb-c interconnect between the two sides. Do you have any plan on releasing the source for those revisions or are just private iterations not ready to be shared?

richerve, 2019-10-05:
Ping @omkbd

JimmyMultani, 2019-10-20:
Hey @omkbd, any plans to release these schematics? Thank you.

MattBlissett, 2019-10-28:
I'd like to make an Ergodash.  Are the two changes above (hot-swappable switches, USB-C) and the rotary encoder (from the other issue and Twitter) the changes expected in r1.3 / r2.0, or is there more?

lucasfperotti, 2019-11-06:
@omkbd Oh my god yes !!! I was about to buy a corne kbd kit just because i could not find a ergo dash with hot swap mx switches but if a 2.0 is going to happen i will get that !!! I am a great fan of this keyboard !

MattBlissett, 2019-11-07:
I just finished making my hot-swap Ergodash (rev 1.2). I used [Mill-Max sockets](https://www.mouser.com/ProductDetail/mill-max/0305-2-15-80-47-80-10-0/), as in [this build](https://www.reddit.com/r/MechanicalKeyboards/comments/bvm3pe/my_first_build_ergodash_with_hotswappable/) ([more detail](https://www.reddit.com/r/MechanicalKeyboards/comments/bvm6zf/my_first_build_ergodash_with_hotswappable/)).

I'm glad I used the slightly longer 0305 sockets, it was less fiddly than I expected. However, the socket for the key above the Pro Micro touches one of the Pro Micro's capacitors, so it's about 0.7mm higher than it should be.

I'm not sure what Falba Tech use, as they sell the Ergodash preassembled with Mill-Max sockets.

Geobert, 2019-11-07:
What I'm super hype on this 2.0 is the 4 keys thumb cluster, so I really hope 2.0 will become a thing!

richerve, 2019-11-12:
@omkbd any update on this?

omkbd, 2019-11-28:
I am very busy now. You will be able to resume development in a little more time.

n8gray, 2019-12-03:
Thanks for the update- count me in with the others who would be thrilled by a socketed design.

NellyWhadsDev, 2020-01-21:
Hey @omkbd any chance this is coming soon? If you need help, I'm more than happy to pitch in any way I can. Dying to get a v2.0 (at least from the teaser pics)

MMMikeM, 2020-07-03:
@omkbd is the project still active?

richerve, 2021-05-19:
As this was mainly a question and haven't been answered in more than a year, will close it.

Closed 2021-05-19.

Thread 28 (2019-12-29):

Is EE_HANDS supported?

BoKKeR, 2019-12-29:
Is EE_Hands supported on the pcb? I cant find anything about it in the documentation. Usually I would tie on one side a pin to high and on the other side to ground.
are any of these pins broken out?

I am using elite-c so I have extra pins and can do it if the pcb does not support it.

BoKKeR, 2020-01-04:
I just wired up an extra pin from the elite-c to high on one side and low on the other.

Closed 2020-01-04.

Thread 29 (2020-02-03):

Making the pcb and case Alps friendly.

oprietop, 2020-02-03:
Hi there!
I'm trying to modify the case cuts to be an hybrid MX/Alps compliant and they only seem to need a little tweak: the upper right screw hole is too close to the right switch and i guess it will overlap with an [Alps switch wing](https://i.imgur.com/GQCLrtT.jpg).

Yo can seem [my edits there](https://github.com/oprietop/ErgoDash/blob/master/Case/rev1.2/ergodash-rev1-2_alps.svg) in the upper top piece.

I think the hole in the pcb hole is it wide enough and could work as is and maybe only moving the hole a milimeter to the left on the cases pieces will do.
Could you consider these kind of changes on a future release or variation of the pcb?

oprietop, 2020-05-23:
I Finally did and testet my own tweaks for this board and other splits, they are here: https://github.com/oprietop/Split-Keyboard-Cases

Here are some pics of the [top](https://github.com/oprietop/Split-Keyboard-Cases/blob/master/images/ergodash_clearance_1.jpg) and [bottom](https://github.com/oprietop/Split-Keyboard-Cases/blob/master/images/ergodash_clearance_2.jpg) clearance with alps switches.

Closed 2020-05-23.

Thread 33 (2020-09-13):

M2 spacers height

GioTB, 2020-09-13:
Hi!, does anyone know what is the height of the m2 spacers?

clembo1, 2020-09-14:
Direct translation from Japanese ala google
https://github.com/omkbd/ErgoDash/blob/master/Doc/Shoplist_JP.md
M2 x 5 mm screw x 22
M2 x 8mm screw x 6
M2 x 6mm spacer x 14

Math:  2 screws per spacer (1 bottom, 1 top)  six (6) 8MM screws uses 3 spacers.  This leaves 11 spacers left.  22 screws / 2 = 11 spacers.  Thus all screws are accounted for.

Only caveat is that the directions on the English guide, Step 11, references "Install the 5mm and 6mm spacers from the top."  Just my guess, but I think it means 5MM screws with the 6MM spacer.

I would also add that the English Parts list for the Screws and Spacers added a lot of confusion for me till I thought things through "M2×8mm screw × 6 M2 spacer × 14".  I think it was typos or translation issue from google translate or some other service.

MattBlissett, 2020-09-14:
The pull request I made fixes all three things -- the missing "mm" after 6, the missing newline, and the missing word "screws" in the build guide.  @omkbd will probably merge it when he sees the notification.

GioTB, 2020-09-14:
Thanks!!!!, that helps a lot!

Closed 2020-09-18.

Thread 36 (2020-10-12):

Hole size for Pro-Micro's too small for Hotswap sockets

clembo1, 2020-10-12:
If there is a future revision of the Ergodash keyboard, would you consider increasing the space size of the holes for the Pro-micro to permit the use of sockets for the pro-micros?  The current fit is quite snug and leaves no room for sockets to be added.

Since pro-micros are hard to de-solder and the keyboard and led connections are covered by the pro-micros, it would be very useful to be able to pull the board off as needed.

An example is from Keebio.  https://keeb.io/products/peel-a-way-sockets-for-pro-micros

clembo1, 2020-12-26:
I went ahead and ordered the hotswap sockets from kebio since it was cheap and I wanted to test the sizing.  What is needed to enable hotswap sockets for the pro-micro is to resize the holes on the keyboard pcb to be the same size as the holes for the LED lights below the key switches.  The proposed change would only apply to the holes for the pro-micro.

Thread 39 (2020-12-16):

Sugestion: Increase extra thumb key connection pads to 4mm each (JLCPCB Audit failing)

rafaeldelboni, 2020-12-16:
I sent the 1.2 gerger files to print in jlcpcb and they asked me to change the file to increase the size of the size of the connections to at least 4mm each.

This could be useful the future users that will send the file to print in this store.

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

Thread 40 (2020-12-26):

Update parts list for M2x6mm spacer to "M2×6mm threaded spacer"

clembo1, 2020-12-26:
1.  M2×6mm spacer.  Should say "M2×6mm threaded spacer"
2. When using the full-size (i.e. both thumb cluster buttons), you need 16 spacers, not 14.

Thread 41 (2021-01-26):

parts says 66-70 keys, couldn't you use 72?

jack-faller, 2021-01-26:
the parts list says 66-70 keys yet, if all 5 keys in the thumb cluster were used, there would be 72. is there some design factor that prevents all 5 from being used?

Strayer, 2021-01-26:
Yes, the way the traces are set up the top keys would be wired together and both trigger the same key in QMK as far as I remember. [I did this without checking the traces and only realized this after finishing the build.](https://www.reddit.com/r/MechanicalKeyboards/comments/es8urx/it_may_not_be_as_pretty_as_others_but_i_finally/ff9t557/)

jack-faller, 2021-01-26:
ok thx

Closed 2021-01-26.

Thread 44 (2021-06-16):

Reset is not working while flashing

MaKaNu, 2021-06-16:
Hi,

I builded Rev1.2 with a few parts switched (Different LEDs because Kailh switches, different SMD LEDs SK6812 because they seemed a good option for the ws2812b). I finally installed all parts and also got my self-made TRRS cable running (I Tested the connections and there is no error in the cable).
My qmk setup:

```bash
multibuild.keymap=default
user.keyboard=ergodash/rev1
user.keymap=makanu
```

And the keymap makanu is at the moment just a copy of the default keymap.

When I use the command ```qmk flash```, the command ends up with ```Detecting USB port, reset your controller now...``` and pressing the reset button doesn't do anything.

Additional I recognized that the switch LEDs on the right side are dimmed. This also happens if I switch master side.

Any hint where I should start measuring with a multimeter, to provide further informations?

MaKaNu, 2022-09-27:
Sadly not until now. My first idea was faulty soldering, but I was unable to find the issue. At the moment I have a de-soldered micro controller which is probably defect, because of the de-soldering. Sadly the project is on stall for me at the moment. I am also not really happy about the soldering position of the micro-controller, since it is so close to the pins.

JonahBranch, 2022-09-27:
I'm wondering if it's an issue with the bootloader. I'm going to try rewriting the bootloader and I'll let you know if that fixes it

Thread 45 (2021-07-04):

Slave Hand RGB Underglow not working

GiannottiRod, 2021-07-04:
Hi,

So, I have built this about 2 months ago now, but RGB LEDs and MOSFETs took a while to get here. I have never had any issues before this. I soldered the main head first and had everything working as soon as I updated my firmware to have a RGB_TOGG. However, when I soldered the slave hand I couldn't get it to light up. I considered the problem could be MOSFET/ MOSFET soldering issue, so I unsoldered it and replaced it for a new one, but still no luck. So I soldered some LEDs to some keys to test the behaviour.

So, now my current situation is:
When I connect the main hand or both only main hand RGB works and both hands 3mm LED work. However, I can only toggle off the LEDs on the main hand.

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

All keys are working perfectly, RGB controls to the main hand also work.

I have a [video](https://imgur.com/a/M0PCJvB) to illustrate the 3mm led only being turned off on the main hand issue.

[EDIT 1] just to clarify, changing the USB cable to my right hand does not change the behaviour. Probably should have changed the issue name to right hand LED not working instead of Slave hand.

GiannottiRod, 2021-07-04:
Ok. I am dumb and forgot to solder 1 pad on the very first RGB LED. lightning works ok now. Right Hand 3mm LED still does not go off. Ill just desolder it.

Closed 2021-07-04.

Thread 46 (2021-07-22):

Underglow RGB LEDs not working on both sides

ryzhkovvv, 2021-07-22:
LEDS are off when I plug the keyboard and don't turn on on the RGB Toggle key press.

This is my first keyboard build, so it might be some stupid mistake, but I'm pretty sure my keyboard soldered correctly, LED jumpers are bridged according to manual and I just refreshed soldering joints on MOSFET, and LEDs. They seem fine.

Here is the photo of the left (master) half of the keyboard:
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

usb79, 2021-07-23:
Hi,
guess I had the same or a similar issue. In my case it was the bus controlling the WS2812 LEDs. Check the connection between each output and input if the solder joints are ok. Measuring between output and corresponding next input of the WS2812 LEDs (on top of the connectors) helps verifying if the LEDs are connected properly.
Good luck, I hope you get it to work soon!

ryzhkovvv, 2021-07-23:
Solved! I'm an idiot, I was flashing my keyboard with firmware in which RGB underflow was disabled, so  RGB Toggle key didn't work either. Now I figured out how to properly turn my json file from Configurator to keymap.c with json2c command in QMK SYS and compiled a normal firmware my underflow works normally.
It was pretty unintuitive, though - that if RGB_Enable is set to 'no' underflow not just disabled by default, but whole RGB functionality is disabled.

Closed 2021-07-24.

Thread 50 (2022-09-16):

Adds led lights for the top edge

phucdzvcll, 2022-09-16:
I want to mount more led on the top edge, but I don't know how to connect the power cord and controller cord?

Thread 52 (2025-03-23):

Error in build guide

F2g-git, 2025-03-23:
I think I might have found a mistake in the build guide FOR v1.2:

In this image:
https://github.com/omkbd/picture/blob/master/diode_complete.jpg

The bottom right diode pair should have only the left diode populated, the right one should be a transistor from the markings on the PCB and the connectivity I derived.

F2g-git, 2025-03-23:
Should have looked, its a 1.1 pcb on the image...

Closed 2025-03-23.

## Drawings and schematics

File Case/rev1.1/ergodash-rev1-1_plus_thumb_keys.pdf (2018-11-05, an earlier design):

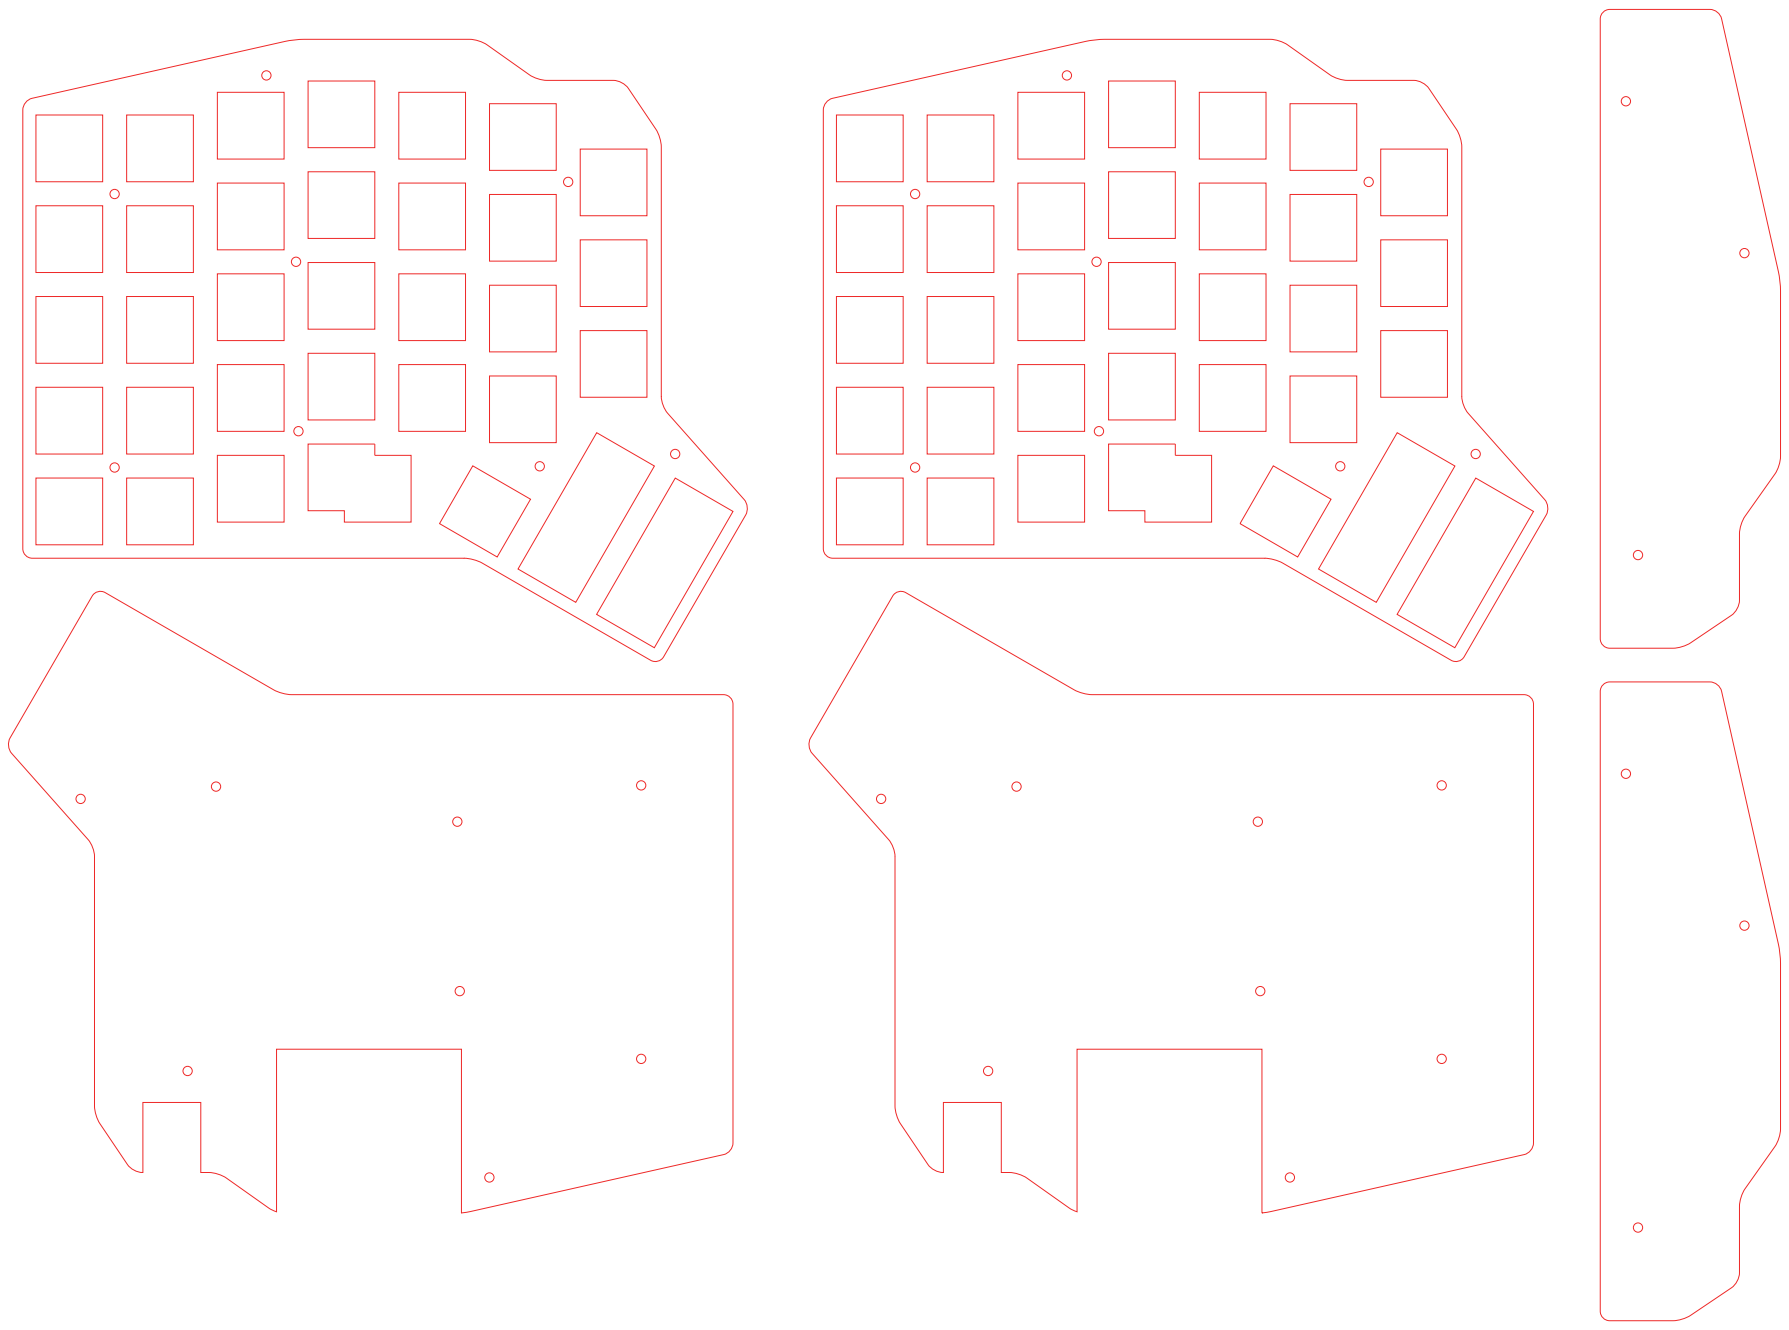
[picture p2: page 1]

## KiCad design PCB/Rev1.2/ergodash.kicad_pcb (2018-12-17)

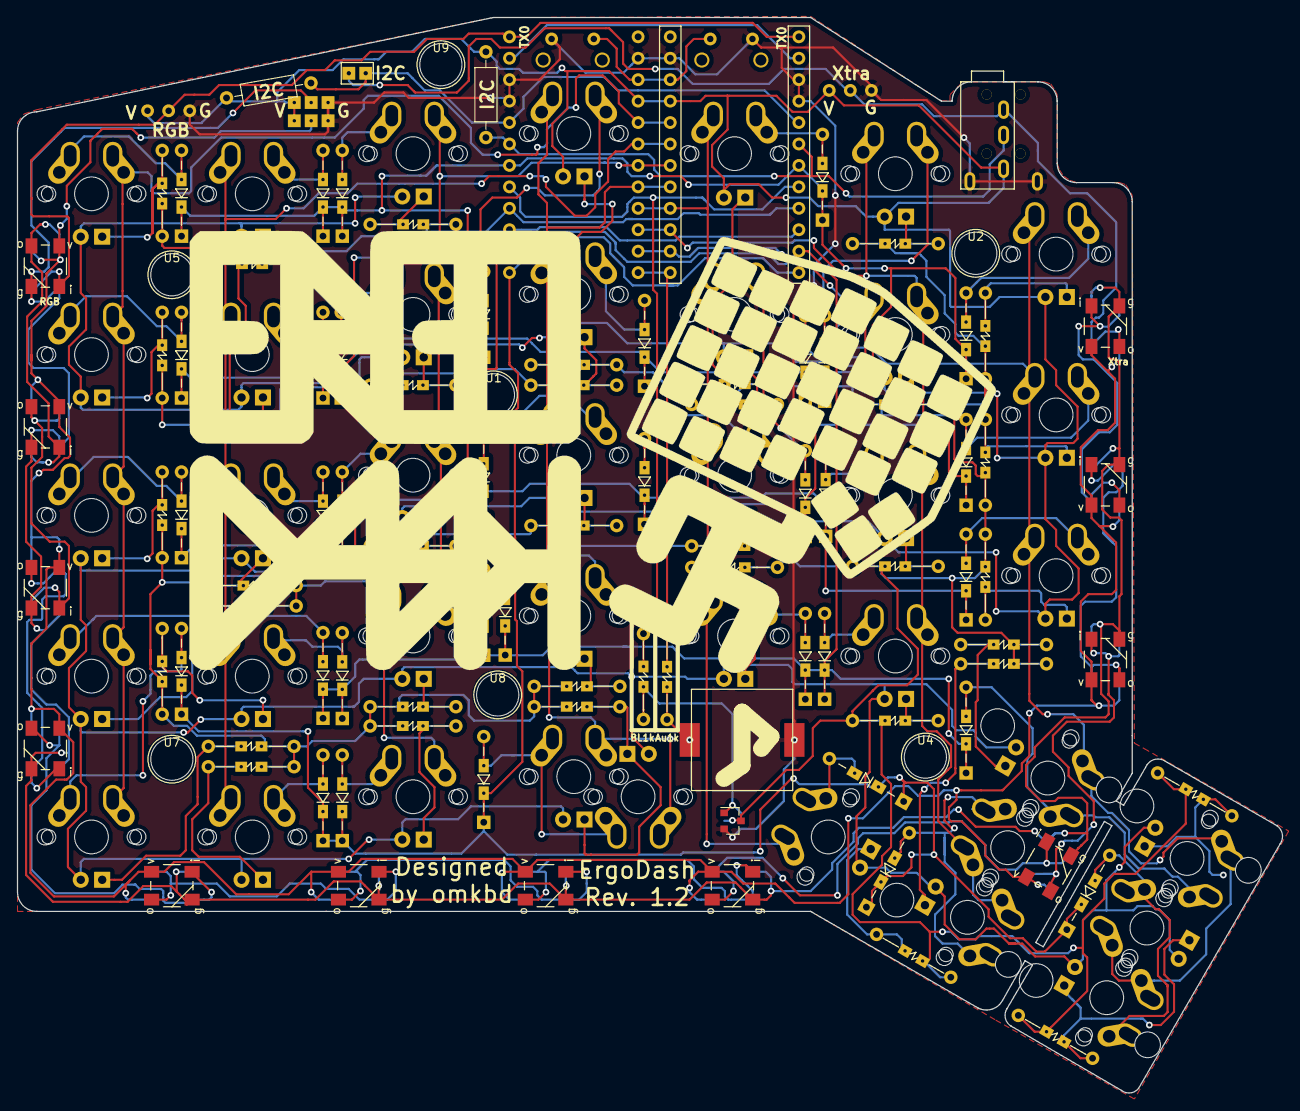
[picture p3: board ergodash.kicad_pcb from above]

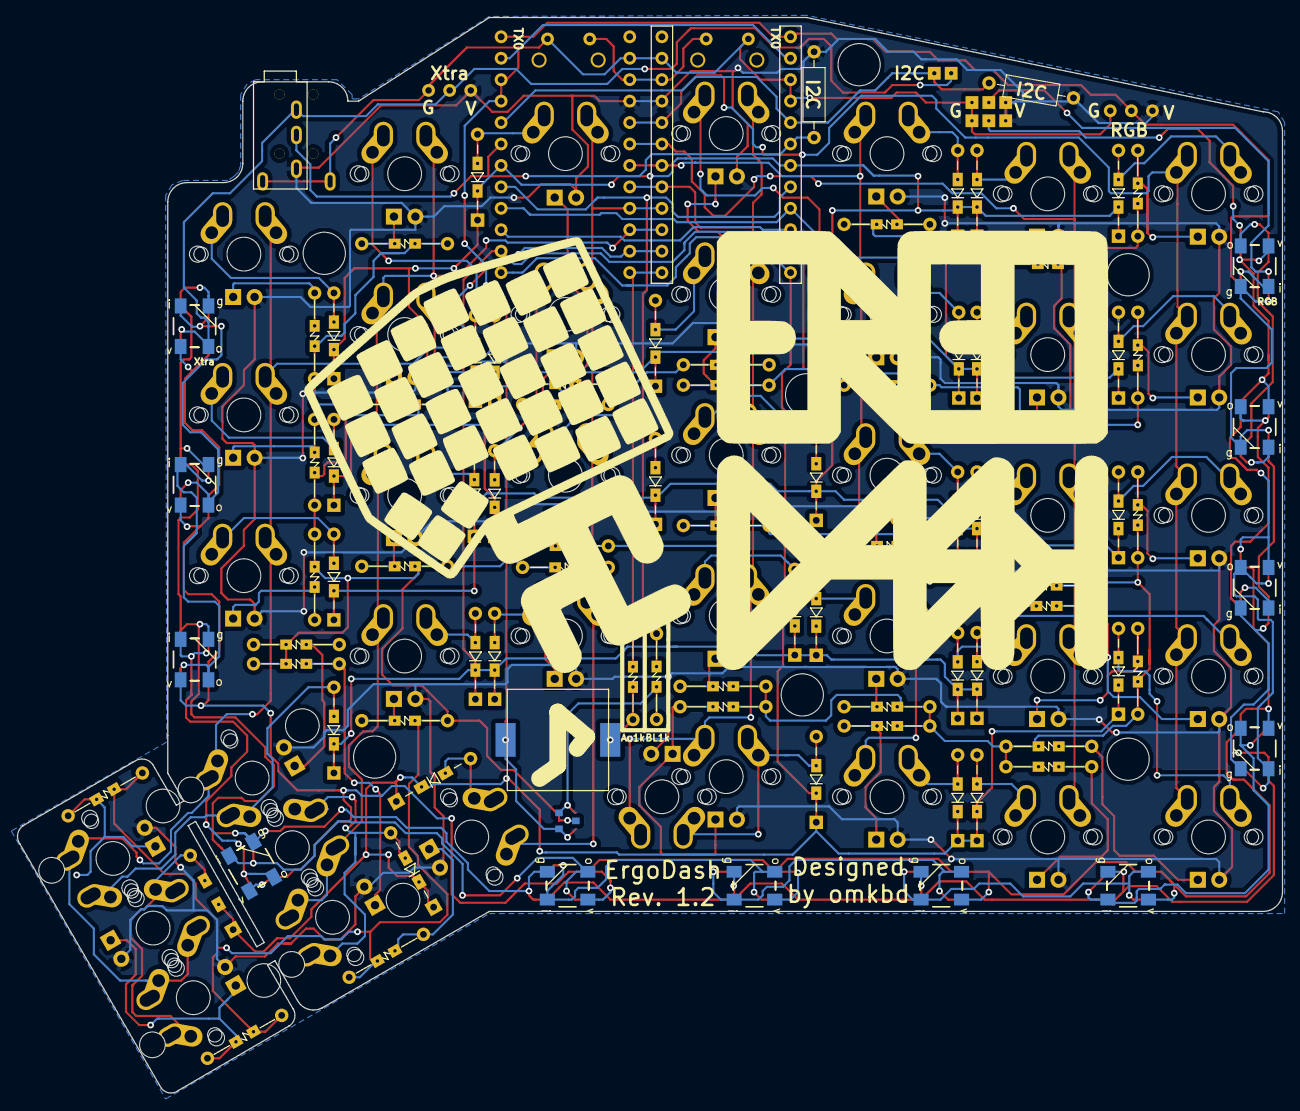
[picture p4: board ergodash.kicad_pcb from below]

Board: 2 copper layers, 149.9 x 127.4 mm, 183 parts (27 on the bottom side), 109 nets.

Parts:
D1, D2, D3, D4, D5, D6, D7, D8, D9, D10, D11, D12, D13, D14, D15, D16, D17, D18, D19, D20, D21, D22, D23, D24, D25, D26, D27, D28, D29, D30, D31, D32, D33, D34: D; Diode_SMD_THT3
D35, D36, D37, D38, D39, D40, D41, D42, D43, D44, D45, D46, D47, D48, D49, D50, D51, D52, D53, D54, D55, D56, D57, D58, D59, D60, D61, D62, D63, D64, D65, D66, D67, D69, D70, D71, D72, D73: LED; CHERRY_MX_LED2
D68: D; Diode_SMD_THT2
J1: 5PIN; trrs_jack2
J2, J3: Conn_01x03; conn3
J4, J5: GS3; jumper2
LED1, LED2, LED3, LED4, LED5, LED6, LED7, LED8, LED9, LED10, LED11, LED12: WS2812B; WS2812B-5
M1: Speaker; PKLCS1212E4001-R1
Q1: IRLML6344TRPbF; SOT-23_2
R1, R2: R; R_Axial_DIN0207_L6.3mm_D2.5mm_P10.16mm_Horizontal
R3, R4, R5, R6, R7, R8, R9, R10, R11, R12, R14, R15, R16, R17, R18, R19, R20, R21, R22, R23, R24, R25, R26, R27, R28, R29, R30, R31, R32, R33, R34, R35, R36, R37, R38, R39: R; Resistors_SMD_THT
R13, R40: 1k; Resistors_SMD_THT
SW1, SW2, SW3, SW4, SW5, SW6, SW7, SW8, SW9, SW10, SW11, SW12, SW13, SW14, SW15, SW16, SW17, SW18, SW19, SW20, SW21, SW22, SW23, SW24, SW25, SW26, SW27, SW28, SW30, SW31, SW32, SW33, SW34, SW35, SW36, SW38, SW39, SW40, SW41: SW_PUSH; MX_ALPS
SW29, SW37: SW_Push; tact_switch2
U1, U2, U4, U5, U7, U8, U9: HOLE; hole
U3, U6: ProMicro; ProMicro_rev
W1: jumper_smd; jumper_smd_2dub

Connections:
/Audio: R40.1, U3.8, U6.8
/Backlight: R13.1, U3.13, U6.13
/RBG: J2.2, LED1.2, U3.1, U6.1
/RX: U3.2, U6.2
/col0: SW1.1, SW2.1, SW3.1, SW4.1, SW30.1, U3.20, U6.20
/col1: SW5.1, SW6.1, SW7.1, SW8.1, SW31.1, U3.19, U6.19
/col2: SW9.1, SW10.1, SW11.1, SW12.1, SW32.1, U3.18, U6.18
/col3: SW13.1, SW14.1, SW15.1, SW16.1, SW33.1, SW38.1, U3.17, U6.17
/col4: SW17.1, SW18.1, SW19.1, SW20.1, SW34.1, U3.16, U6.16
/col5: SW21.1, SW22.1, SW23.1, SW24.1, SW35.1, SW36.1, U3.15, U6.15
/col6: SW25.1, SW26.1, SW27.1, SW28.1, SW39.1, SW40.1, SW41.1, U3.14, U6.14
/row0: D1.1, D5.1, D9.1, D13.1, D17.1, D21.1, D25.1, U3.7, U6.7
/row1: D2.1, D6.1, D10.1, D14.1, D18.1, D22.1, D26.1, U3.9, U6.9
/row2: D3.1, D7.1, D11.1, D15.1, D19.1, D23.1, D27.1, U3.10, U6.10
/row3: D4.1, D8.1, D12.1, D16.1, D20.1, D24.1, D28.1, U3.11, U6.11
/row4: D29.1, D30.1, D31.1, D32.1, D33.1, D34.1, D68.1, U3.12, U6.12
/rst: SW29.1, SW37.1, U3.22, U6.22
/scl: R1.2, U3.5, U6.5, W1.2
/sda/uart: J1.3, R2.2, U3.6, U6.6
/xtradata: J1.2, J3.2, LED12.4, W1.1
GND: J1.4, J1.5, J2.3, J3.3, J4.3, J5.3, M1.1, Q1.2, SW29.2, SW37.2, U3.3, U3.4, U3.23, U6.3, U6.4, U6.23
unnamed: D1.2, SW1.2
unnamed: D2.2, SW2.2
unnamed: D3.2, SW3.2
unnamed: D4.2, SW4.2
unnamed: D5.2, SW5.2
unnamed: D6.2, SW6.2
unnamed: D7.2, SW7.2
unnamed: D8.2, SW8.2
unnamed: D9.2, SW9.2
unnamed: D10.2, SW10.2
unnamed: D11.2, SW11.2
unnamed: D12.2, SW12.2
unnamed: D13.2, SW13.2
unnamed: D14.2, SW14.2
unnamed: D15.2, SW15.2
unnamed: D16.2, SW16.2
unnamed: D17.2, SW17.2
unnamed: D18.2, SW18.2
unnamed: D19.2, SW19.2
unnamed: D20.2, SW20.2
unnamed: D21.2, SW21.2
unnamed: D22.2, SW22.2
unnamed: D23.2, SW23.2
unnamed: D24.2, SW24.2
unnamed: D25.2, SW25.2
unnamed: D26.2, SW26.2
unnamed: D27.2, SW27.2
unnamed: D28.2, SW28.2, SW39.2
unnamed: D29.2, SW30.2
unnamed: D30.2, SW31.2
unnamed: D31.2, SW32.2
unnamed: D32.2, SW33.2, SW38.2
unnamed: D33.2, SW34.2
unnamed: D34.2, SW35.2, SW36.2
unnamed: D35.1, R3.1
unnamed: D36.1, R4.1
unnamed: D37.1, R5.1
unnamed: D38.1, R6.1
unnamed: D39.1, R7.1
unnamed: D40.1, R8.1
unnamed: D41.1, R9.1
unnamed: D42.1, R10.1
unnamed: D43.1, R11.1
unnamed: D44.1, R12.1
unnamed: D45.1, R15.1
unnamed: D46.1, R16.1
unnamed: D47.1, R17.1
unnamed: D48.1, R18.1
unnamed: D49.1, R19.1
unnamed: D50.1, R20.1
unnamed: D51.1, R21.1
unnamed: D52.1, R22.1
unnamed: D53.1, R23.1
unnamed: D54.1, R24.1
unnamed: D55.1, R25.1
unnamed: D56.1, R26.1
unnamed: D57.1, R27.1
unnamed: D58.1, R28.1
unnamed: D59.1, R29.1
unnamed: D60.1, R30.1
unnamed: D61.1, R31.1
unnamed: D62.1, R32.1
unnamed: D63.1, R33.1
unnamed: D64.1, R34.1
unnamed: D65.1, R35.1
unnamed: D66.1, D67.1, R36.1
unnamed: D68.2, SW40.2, SW41.2
unnamed: D69.1, R14.1
unnamed: D70.1, R37.1
unnamed: D71.1, R38.1
unnamed: D72.1, D73.1, R39.1
unnamed: J4.2, LED1.1, LED2.1, LED3.1, LED4.1, LED5.1, LED6.1, LED7.1, LED8.1, LED9.1, LED10.1, LED11.1, LED12.1
unnamed: J5.2, LED1.3, LED2.3, LED3.3, LED4.3, LED5.3, LED6.3, LED7.3, LED8.3, LED9.3, LED10.3, LED11.3, LED12.3
unnamed: LED1.4, LED2.2
unnamed: LED2.4, LED3.2
unnamed: LED3.4, LED4.2
unnamed: LED4.4, LED5.2
unnamed: LED5.4, LED6.2
unnamed: LED6.4, LED7.2
unnamed: LED7.4, LED8.2
unnamed: LED8.4, LED9.2
unnamed: LED9.4, LED10.2
unnamed: LED10.4, LED11.2
unnamed: LED11.4, LED12.2
unnamed: M1.2, R40.2
unnamed: Q1.1, R13.2
unnamed: Q1.3, R3.2, R4.2, R5.2, R6.2, R7.2, R8.2, R9.2, R10.2, R11.2, R12.2, R14.2, R15.2, R16.2, R17.2, R18.2, R19.2, R20.2, R21.2, R22.2, R23.2, R24.2, R25.2, R26.2, R27.2, R28.2, R29.2, R30.2, R31.2, R32.2, R33.2, R34.2, R35.2, R36.2, R37.2, R38.2, R39.2
VCC: D35.2, D36.2, D37.2, D38.2, D39.2, D40.2, D41.2, D42.2, D43.2, D44.2, D45.2, D46.2, D47.2, D48.2, D49.2, D50.2, D51.2, D52.2, D53.2, D54.2, D55.2, D56.2, D57.2, D58.2, D59.2, D60.2, D61.2, D62.2, D63.2, D64.2, D65.2, D66.2, D67.2, D69.2, D70.2, D71.2, D72.2, D73.2, J1.1, J2.1, J3.1, J4.1, J5.1, R1.1, R2.1, U3.21, U6.21

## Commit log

2018-06-30 Add Case and PCB folder
2018-07-01 add PCB and Case
    [ergodash-B.Cu.gbl, ergodash-B.Mask.gbs, ergodash-B.SilkS.gbo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]
2018-07-02 add spring pin
2018-07-03 180703 PCB readme
2018-08-07 add rev.1.1
    [ergodash-B.Cu.gbl, ergodash-B.Mask.gbs, ergodash-B.SilkS.gbo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]
2018-08-07 add 買い物リスト
2018-08-30 add assembly
2018-09-16 add notice when using spring header
2018-09-17 fix readme
    販売情報の追加
2018-09-19 add case data
2018-10-27 add mini case data
2018-12-17 add gerber data
    [ergodash.drl, ergodash.gbl, ergodash.gbo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]
2018-12-17 add kicad data
    [ergodash.kicad_pcb, ergodash.sch]
2019-02-03 Add files via upload
    Used Microsoft Translate to follow instructions and build my board. Took the translation and added notes from my build experience
2019-05-04 最新ファームウェア用に修正
2019-05-12 ErgoDash mini has 20 LEDs
2020-04-13 fixed stabileser hole for 3mm aclic plate
2020-04-13 fixed stabiliser hole for 3mm aclic plate
2020-04-15 fixed ergodash-mini 2U stabiliser hole
2020-09-01 Add a notice about Underglow LEDs and Backlight LEDs.
2020-09-13 Spacers: make the English list and guide the same as the Japanese.
    Resolves #26
    Resolves #33
